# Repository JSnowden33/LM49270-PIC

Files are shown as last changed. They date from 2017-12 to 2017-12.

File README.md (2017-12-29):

# LM49270-PIC
This is a program allowing for digital or analog volume control on the LM49270 headphone/speaker amplifier using a PIC16F1503 microcontroller.
It is in the form of an MPLAB X project and can be compiled using MPLAB X IDE with XC8. You can also use the pre-compiled program found at
Software/LM49270-PIC.X/dist/default/production/LM49270-PIC.X.production.hex with MPLAB IPE. The board can be programmed using a PICkit 3.

The program allows for 32 steps of volume. Speaker volume is allowed the full range from 0 to 31. Headphone volume is restricted from 0 to 21. This can be changed by modifying HP_OFFSET in Config.h.

The operating mode is selected by soldering a jumper located behind the headphone jack on the PCB. When soldered to GND, it operates in digital mode and volume is controlled with two tact switches connected between UP/DN and GND. When the jumper is soldered to V+, it operates in analog mode and volume is controlled with a potentiometer soldered to V+, VOL, and GND.

The PCB for this circuit can be ordered here: https://oshpark.com/shared_projects/Wy4lnqzu  
The circuit requires 3.3V to 5V input. It uses a headphone jack with a NC switch. Speaker output is automatically toggled off by hardware when headphones are detected. The amp works best with speakers between 0.7W and 1.2W.

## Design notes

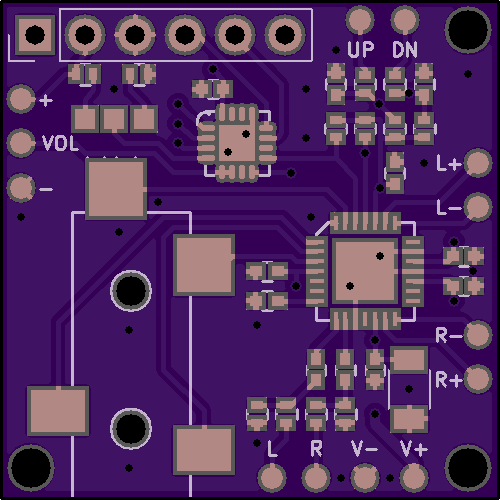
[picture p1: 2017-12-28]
PCB/PCB Front.png

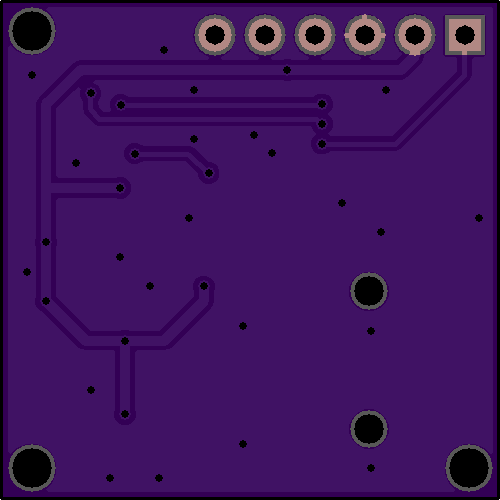
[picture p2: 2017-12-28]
PCB/PCB Back.png

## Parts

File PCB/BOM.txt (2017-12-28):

Components can be bought from Digikey or Mouser

1 x 10 uF 1206 capacitor (TMCMA1C106MTRF)
11 x 1 uF 0402 capacitor (GRM155R61C105MA12D)
8 x 4.7K 0402 resistor (RC0402FR-074K7L)
2 x 10K 0402 resistor (RC0402FR-0710KL)
2 x 22 ohm 0402 resistor (RC0402JR-0722RL)
1 x Headphone Jack (SJ-3524-SMT-TR)
1 x PIC16F1503 QFN-16 (PIC16F1503-I/MG)
1 x LM49270 QFN-28 (LM49270SQ/NOPB)

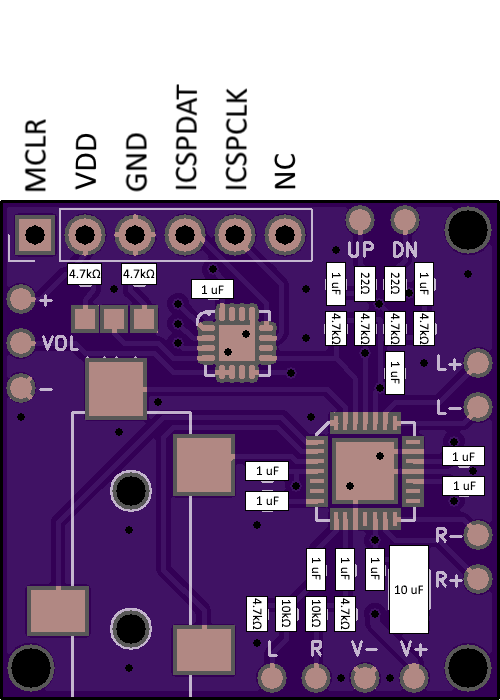
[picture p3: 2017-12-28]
PCB/Components.png

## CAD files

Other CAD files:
Software/LM49270-PIC.X/dist/default/production/LM49270-PIC.X.production.obj

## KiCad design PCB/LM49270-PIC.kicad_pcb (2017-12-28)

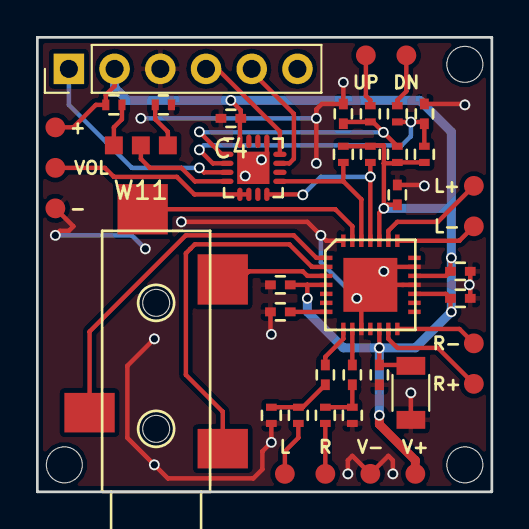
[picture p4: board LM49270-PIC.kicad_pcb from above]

Board: 2 copper layers, 25.2 x 25.2 mm, 47 parts (0 on the bottom side), 30 nets.

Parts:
C1, C2, C3, C4, C5, C6, C7, C8, C9, C11, C12: C; C_0402
C10: CP; C_1206
J1: JACK_TRS_4PINS; SJ-3524-SMT-TR
J2: CONN_01X06; Pin_Header_Straight_1x06_Pitch2.54mm
R1, R2, R3, R4, R5, R6, R7, R8, R9, R10, R11, R12: R; R_0402
Screw: Screw
Screw#2, Screw#3: Screw
U1: PIC16F1503; QFN-16-1EP_3x3mm_Pitch0.5mm
U2: LM49270; QFN-28-LM49270
W1, W2, W3, W4, W5, W6, W7, W8, W9, W10, W11, W12, W13, W14, W15, W16: TEST_1P; Pad

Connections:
GND: C1.1, C4.2, C5.2, C6.2, C7.1, C8.1, C9.2, C10.2, C11.1, C12.1, J2.3, R1.2, R5.2, R12.2, U1.13, U1.17, U2.10, U2.18, U2.20, U2.28, U2.29, W5.1, W16.1
unnamed: C1.2, R6.1, R10.1, U1.1
unnamed: C2.1, U2.8
unnamed: C2.2, R1.1, R3.1
unnamed: C3.1, U2.9
unnamed: C3.2, R4.1, R5.1
unnamed: C6.1, U2.7
unnamed: C7.2, R2.2, R11.2, U1.2
unnamed: J1.1, U2.2
unnamed: J1.2, U2.3
unnamed: J1.3, U2.1
unnamed: J1.4, U2.27
unnamed: J2.1, U1.3
unnamed: J2.4, U1.12
unnamed: J2.5, U1.11
unnamed: R2.1, W6.1
unnamed: R3.2, W2.1
unnamed: R4.2, W3.1
unnamed: R6.2, W1.1
unnamed: R7.1, U1.8, U2.25
unnamed: R8.1, U1.9, U2.26
unnamed: R9.2, W15.1
unnamed: R12.1, W13.1
unnamed: U1.4, W11.1
unnamed: U1.5, U1.6, W12.1
unnamed: U2.13, W10.1
unnamed: U2.14, W9.1
unnamed: U2.22, W8.1
unnamed: U2.23, W7.1
VDD: C4.1, C5.1, C8.2, C9.1, C10.1, C11.2, C12.2, J2.2, R7.2, R8.2, R9.1, R10.2, R11.1, U1.16, U2.4, U2.12, U2.17, U2.19, U2.24, W4.1, W14.1

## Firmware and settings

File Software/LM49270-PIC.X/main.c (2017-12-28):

/*
 * File:   main.c
 * Author: Jackson Snowden
 */

#include <xc.h>
#include "Config.h"
#include "I2C.h"

signed int vol;
unsigned int SP_vol;
unsigned int HP_vol;

unsigned char PWR_state;
unsigned char mode;

// CONFIG1
#pragma config FOSC = INTOSC    // Oscillator Selection Bits (INTOSC oscillator: I/O function on CLKIN pin)
#pragma config WDTE = OFF       // Watchdog Timer Enable (WDT disabled)
#pragma config PWRTE = OFF      // Power-up Timer Enable (PWRT disabled)
#pragma config MCLRE = ON       // MCLR Pin Function Select (MCLR/VPP pin function is MCLR)
#pragma config CP = OFF         // Flash Program Memory Code Protection (Program memory code protection is disabled)
#pragma config BOREN = ON       // Brown-out Reset Enable (Brown-out Reset enabled)
#pragma config CLKOUTEN = OFF   // Clock Out Enable (CLKOUT function is disabled. I/O or oscillator function on the CLKOUT pin)

// CONFIG2
#pragma config WRT = OFF        // Flash Memory Self-Write Protection (Write protection off)
#pragma config STVREN = ON      // Stack Overflow/Underflow Reset Enable (Stack Overflow or Underflow will cause a Reset)
#pragma config BORV = LO        // Brown-out Reset Voltage Selection (Brown-out Reset Voltage (Vbor), low trip point selected.)
#pragma config LPBOR = OFF      // Low-Power Brown Out Reset (Low-Power BOR is disabled)
#pragma config LVP = ON         // Low-Voltage Programming Enable (Low-voltage programming enabled)

void PIC_Init()
{
    // Internal oscillator enabled at 4 MHz
    OSCCON = 0b11101010;
    
    // Enable IOC for RA4 and RA5
    IOCAP = 0b00000000;
    IOCAN = 0b00110000;
    IOCAF = 0x00;
    INTCON = 0b10001000;
    
    // Pull-ups disabled
    nWPUEN = 1;     
    
    // Timer 0 no prescaler
    TMR0CS = 1;
    PSA = 1;
    
    // All I/O are input
    TRISA = 0xFF;
    TRISC = 0xFF;
    
    // RC3 is analog input
    ANSELA = 0b00000000;
    ANSELC = 0b00001000;
    
    // Set VREF to VDD  
    ADCON1 = 0b11010000;    
}

unsigned int Read_ADC(unsigned char channel)
{   
    unsigned int result;

    // Turn on A/D module, set channel to specified channel
    ADCON0 = 0b00000001 | (channel << 2);   

    __delay_ms(5);                          // Wait for sampling cap to charge
    GO_nDONE = 1;                           // Start conversion
    while (GO_nDONE == 1);                  // Wait for conversion
    result = (ADRESH << 8) | ADRESL;        // Right-justified, 10-bit result
    
    return result;
}

void LM_Write(unsigned char reg, char data)
{
    I2C_Master_Start();
    I2C_Master_Write(LM_ADDR << 1);            
    I2C_Master_Write(reg | (data & 0x1F));    
    I2C_Master_Stop();
}

void Set_Volume()
{
    LM_Write(SP_REG, SP_vol);
    LM_Write(HP_REG, HP_vol);
    
    // Power off the amp if it's on and volume is 0
    if ((PWR_state == 1) && (vol == 0))
    {
        LM_Write(CNT_REG, 0x02);
        PWR_state = 0;
    }
    
    // Power on the amp if it's off and volume increases
    if ((PWR_state == 0) && (vol != 0))
    {
        LM_Write(CNT_REG, 0x03);
        PWR_state = 1;
    }
}

void Volume_Up()
{
    if (vol < 31)
        vol++;
    else
        vol = 31;
        
    SP_vol = vol;
    
    if (vol > HP_OFFSET)
        HP_vol = vol - HP_OFFSET;
    else
        HP_vol = 0;
}

void Volume_Down()
{
    if (vol > 0)
        vol--;
    else
        vol = 0;
    
    SP_vol = vol;
        
    if (vol > HP_OFFSET)
        HP_vol = vol - HP_OFFSET;
    else
        HP_vol = 0;
}

void Check_ADC()
{
    // Convert 10-bit ADC reading to a 5-bit value
    unsigned int ADC_val = Read_ADC(ADC_IN) >> 5;
    
    if (ADC_val != vol)
    {
        vol = ADC_val;
        
        SP_vol = vol;
        
        if (vol > HP_OFFSET)
            HP_vol = vol - HP_OFFSET;
        else
            HP_vol = 0;
        
        Set_Volume();
    }
}

void LM_Init()
{
    // Headphone and speaker 3D effect off, charge pump enabled, device power on
    LM_Write(CNT_REG, 0x03);
    PWR_state = 1;
  
    // Get initial volume from potentiometer or from stored value
    if (mode)
    {
        Check_ADC();
    }
    else
    {
        vol = INIT_VOL;
        SP_vol = vol;
        HP_vol = vol - HP_OFFSET;
    }
    
    // Set initial volume
    Set_Volume();
}

void interrupt ISR()
{
    // If BUTTON_UP has been pressed
    if (IOCAF5)
    {
        // Start counting with Timer 0
        unsigned int count = 0;
        TMR0 = 0x00;
        TMR0IF = 0;
        TMR0CS = 0;
        
        // Hang until button has been held for ~50ms
        while ((!BUTTON_UP) && (count < 200))
        {
            if (TMR0IF)
            {
                count++;
                TMR0IF = 0;
            }
        }
        
        // Clear timer
        TMR0CS = 1;
        TMR0IF = 0;
        TMR0 = 0x00;
        
        // Increase volume if button was held for over 50ms
        if (count >= 200)
        {
            Volume_Up();
            Set_Volume();
            count = 0;
        }
        
        // Check if button is still pressed
        if (!BUTTON_UP)
        {
            // Start counting with Timer 0
            count = 0;
            TMR0 = 0x00;
            TMR0IF = 0;
            TMR0CS = 0;
            
            // Increase volume every 250ms as long as button is pressed
            while (!BUTTON_UP)
            {
                if (TMR0IF)
                {
                    count++;
                    TMR0IF = 0;
                }
                
                if (count >= 1000)
                {
                    Volume_Up();
                    Set_Volume();
                    count = 0;
                }
            }
            
            // Clear timer
            TMR0CS = 1;
            TMR0IF = 0;
            TMR0 = 0x00;
        }
        
        IOCAF5 = 0;
    }
    
    // If BUTTON_DN has been pressed
    if (IOCAF4)
    {
        // Start counting with Timer 0
        unsigned int count = 0;
        TMR0 = 0x00;
        TMR0IF = 0;
        TMR0CS = 0;
        
        // Hang until button has been held for ~50ms
        while ((!BUTTON_DN) && (count < 200))
        {
            if (TMR0IF)
            {
                count++;
                TMR0IF = 0;
            }
        }
        
        // Clear timer
        TMR0CS = 1;
        TMR0IF = 0;
        TMR0 = 0x00;
        
        // Decrease volume if button was held for over 50ms
        if (count >= 200)
        {
            Volume_Down();
            Set_Volume();
            count = 0;
        }
        
        // Check if button is still pressed
        if (!BUTTON_DN)
        {
            // Start counting with Timer 0
            count = 0;
            TMR0 = 0x00;
            TMR0IF = 0;
            TMR0CS = 0;
            
            // Decrease volume every 250ms as long as button is pressed
            while (!BUTTON_DN)
            {
                if (TMR0IF)
                {
                    count++;
                    TMR0IF = 0;
                }
                
                if (count >= 1000)
                {
                    Volume_Down();
                    Set_Volume();
                    count = 0;
                }
            }
            
            // Clear timer
            TMR0CS = 1;
            TMR0IF = 0;
            TMR0 = 0x00;
        }
        
        IOCAF4 = 0;
    }
    
}

void main()
{
    PIC_Init();
    
    // Set mode on startup based on the select pin
    mode = MODE_SELECT;
    
    // Disable interrupts if mode = 1 so buttons don't work
    if (mode)
    {
        INTCON = 0x00;
    }
    
    // Initialize I2C Master with 100kHz clock
    I2C_Master_Init(100000);  
    
    // Set initial volume and settings
    LM_Init();
     
    while(1)
    {    
        if (mode)
        {
            // Check potentiometer every 100ms
            Check_ADC();
            __delay_ms(100);
        }
    }
}

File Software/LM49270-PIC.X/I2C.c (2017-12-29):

/*
 * File:   I2C.c
 * Author: Jackson Snowden
 */

#include <xc.h>
#include "I2C.h"
#include "Config.h"

void I2C_Master_Init(const unsigned long clk)
{
    SSP1CON1 = 0b00101000;
    SSP1CON2 = 0x00;
    SSP1ADD = (_XTAL_FREQ / (4*clk)) - 1;
    SSP1STAT = 0b10000000;
}

void I2C_Master_Wait()
{
    while ((SSP1STAT & 0x04) || (SSP1CON2 & 0x1F));
}

void I2C_Master_Start()
{
    //SSP1CON2bits.RCEN = 0;
    I2C_Master_Wait();
    SSP1CON2bits.SEN = 1;
}

void I2C_Master_Repeated_Start()
{
    I2C_Master_Wait();
    SSP1CON2bits.RSEN = 1;
}

void I2C_Master_Stop()
{
    //SSP1CON2bits.RCEN = 0;
    I2C_Master_Wait();
    SSP1CON2bits.PEN = 1;
}

void I2C_Master_Write(unsigned char data)
{
    //SSP1CON2bits.RCEN = 0;
    I2C_Master_Wait();
    SSP1BUF = data;
}

void I2C_Master_Ack()
{
    SSP1CON2bits.ACKDT = 0;
    SSP1CON2bits.ACKEN = 1;
}

void I2C_Master_nAck()
{
    SSP1CON2bits.ACKDT = 1;
    SSP1CON2bits.ACKEN = 1;
}

unsigned char I2C_Master_Read(char ack)
{
    I2C_Master_Wait();
    SSP1CON2bits.RCEN = 1;
    I2C_Master_Wait();
    
    unsigned char data = SSP1BUF;
    I2C_Master_Wait();
    
    if (ack)
        I2C_Master_nAck();
    else
        I2C_Master_Ack();
    
    return data;
}
